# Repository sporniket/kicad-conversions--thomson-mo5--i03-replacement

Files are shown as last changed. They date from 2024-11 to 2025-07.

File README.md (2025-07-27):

# Replacement of I03 (color PROM) for the Thomson MO5

> [WARNING] Please read carefully this note before using this project. It contains important facts.

Content

1. What is **Replacement of I03 (color PROM) for the Thomson MO5**, and when to use it ?
2. What should you know before using **Replacement of I03 (color PROM) for the Thomson MO5** ?
3. How to use **Replacement of I03 (color PROM) for the Thomson MO5** ?
4. Known issues
5. Miscellanous

## 1. What is **Replacement of I03 (color PROM) for the Thomson MO5**, and when to use it ?

**Replacement of I03 (color PROM) for the Thomson MO5** replaces the PROM that is used to convert pixel colors represented as a 4 bits value (pastel, red, green, blue) and a supplemental bit for blanking signal, into a RGB-222 value and a supplemental trigger signal for the builtin analog video incrustation feature (requires a specific extension) of the Thomson MO5.

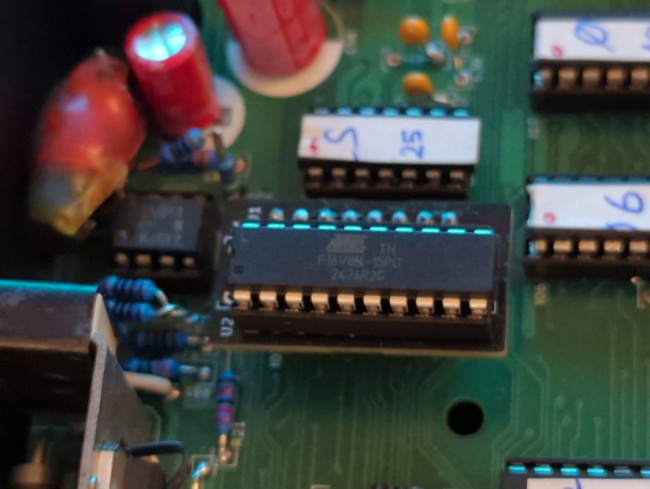
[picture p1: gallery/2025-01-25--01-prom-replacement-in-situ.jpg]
The replacement installed on the motherboard


### Licence

**Replacement of I03 (color PROM) for the Thomson MO5** is published under the Creative Commons CC0 license. You can find a copy of the licence there : https://creativecommons.org/publicdomain/zero/1.0/legalcode

You can copy, modify, distribute and perform the work, even for commercial purposes, all without asking permission.

**Replacement of I03 (color PROM) for the Thomson MO5** is distributed in the hope that it will be useful, but WITHOUT ANY WARRANTY; without even the implied warranty of MERCHANTABILITY or FITNESS FOR A PARTICULAR PURPOSE.

### Release notes

#### Release v2.0.0

* Resolves #6 : Add a breakout connector with R[1..2], V[1..2] and B[1..2] for adding custom DAC mods

Contains schematics in PDF files, gerber archive, and the JED file.

#### Release v1.0.0

Contains schematics in PDF files, gerber archive, and the JED file.

#### Release v1.0.0-rc1

**Hardware only** 

Contains schematics in PDF files, and gerber archive.

## 2. What should you know before using **Replacement of I03 (color PROM) for the Thomson MO5** ?

**Replacement of I03 (color PROM) for the Thomson MO5** is made of an hardware part to hold a GAL16v8 (or its current available compatible component ATF16v8) hereafter called "GAL", and a fusemap to be flashed onto said GAL.

* The hardware part is a Kicad 8 project describing the adapter from original chip socket in the computer motherboard
* The fusemap part is a source to be compiled by relevant tool to obtain a suitable JED fusemap.

> Do not use **Replacement of I03 (color PROM) for the Thomson MO5** if this project is not suitable for your project.

## 3. How to use **Replacement of I03 (color PROM) for the Thomson MO5** ?

### From sources

To get the latest available work, one must clone the git repository.

	git clone --recurse-submodules https://github.com/sporniket/kicad-conversions--thomson-mo5--i03-replacement.git

Then, open the project with Kicad 8.

To produce the fusemap... TO BE WRITTEN

## 4. Known issues
See the [project issues](https://github.com/sporniket/kicad-conversions--thomson-mo5--i03-replacement/issues) page.

## 5. Miscellanous

### Report issues
Use the [project issues](https://github.com/sporniket/kicad-conversions--thomson-mo5--i03-replacement/issues) page.

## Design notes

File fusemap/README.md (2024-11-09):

# Fusemap project

This folder will contains the source description of the fusemap to program into the GAL16v8 to be installed.

For now it is in a draft state (akin to a memo), and contains 2 versions :

* a GALasm compatible candidate description : prom.pld
* A Amaranth compatible candidate description : prom.py

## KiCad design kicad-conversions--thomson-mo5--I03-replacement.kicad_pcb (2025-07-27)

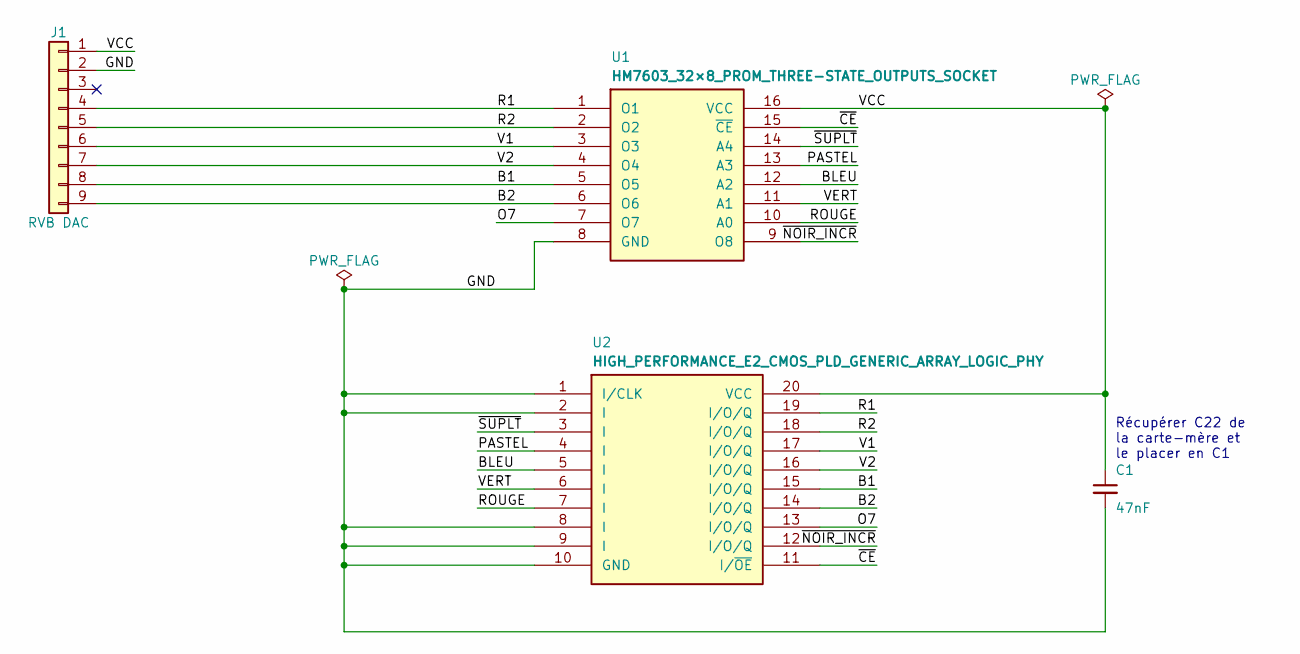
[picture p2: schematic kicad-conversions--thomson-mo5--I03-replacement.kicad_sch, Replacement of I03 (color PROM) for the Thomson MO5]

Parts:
C1: 47nF; Passive_THT_capacitor_mlcc_W2.54mm_L5.08mm
J1: RVB DAC; PinHeader_1x09_P2.54mm_Vertical
U1: HM7603_32×8_PROM_THREE-STATE_OUTPUTS_SOCKET; DIP-16_W7.62mm_LongPads
U2: HIGH_PERFORMANCE_E2_CMOS_PLD_GENERIC_ARRAY_LOGIC_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; DIP-20_W7.62mm_LongPads

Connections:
/B1: J1.8, U1.5 (O5), U2.15 (I/O/Q)
/B2: J1.9, U1.6 (O6), U2.14 (I/O/Q)
/BLEU: U1.12 (A2), U2.5 (I)
/GND: C1.2, J1.2, U1.8 (GND), U2.1 (I/CLK), U2.2 (I), U2.8 (I), U2.9 (I), U2.10 (GND)
/O7: U1.7 (O7), U2.13 (I/O/Q)
/PASTEL: U1.13 (A3), U2.4 (I)
/R1: J1.4, U1.1 (O1), U2.19 (I/O/Q)
/R2: J1.5, U1.2 (O2), U2.18 (I/O/Q)
/ROUGE: U1.10 (A0), U2.7 (I)
/V1: J1.6, U1.3 (O3), U2.17 (I/O/Q)
/V2: J1.7, U1.4 (O4), U2.16 (I/O/Q)
/VCC: C1.1, J1.1, U1.16 (VCC), U2.20 (VCC)
/VERT: U1.11 (A1), U2.6 (I)
/~CE: U1.15 (~CE), U2.11 (I/~OE)
/~NOIR_INCR: U1.9 (O8), U2.12 (I/O/Q)
/~SUPLT: U1.14 (A4), U2.3 (I)

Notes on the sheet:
Récupérer C22 de la carte-mère et le placer en C1

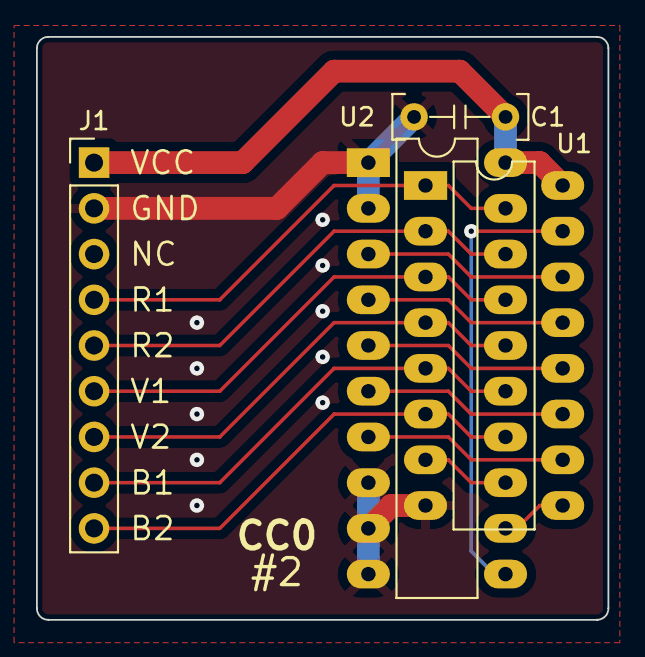
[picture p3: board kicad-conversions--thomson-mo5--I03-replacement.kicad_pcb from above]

Board: 2 copper layers, 31.8 x 32.4 mm, 4 parts (0 on the bottom side), 16 nets.

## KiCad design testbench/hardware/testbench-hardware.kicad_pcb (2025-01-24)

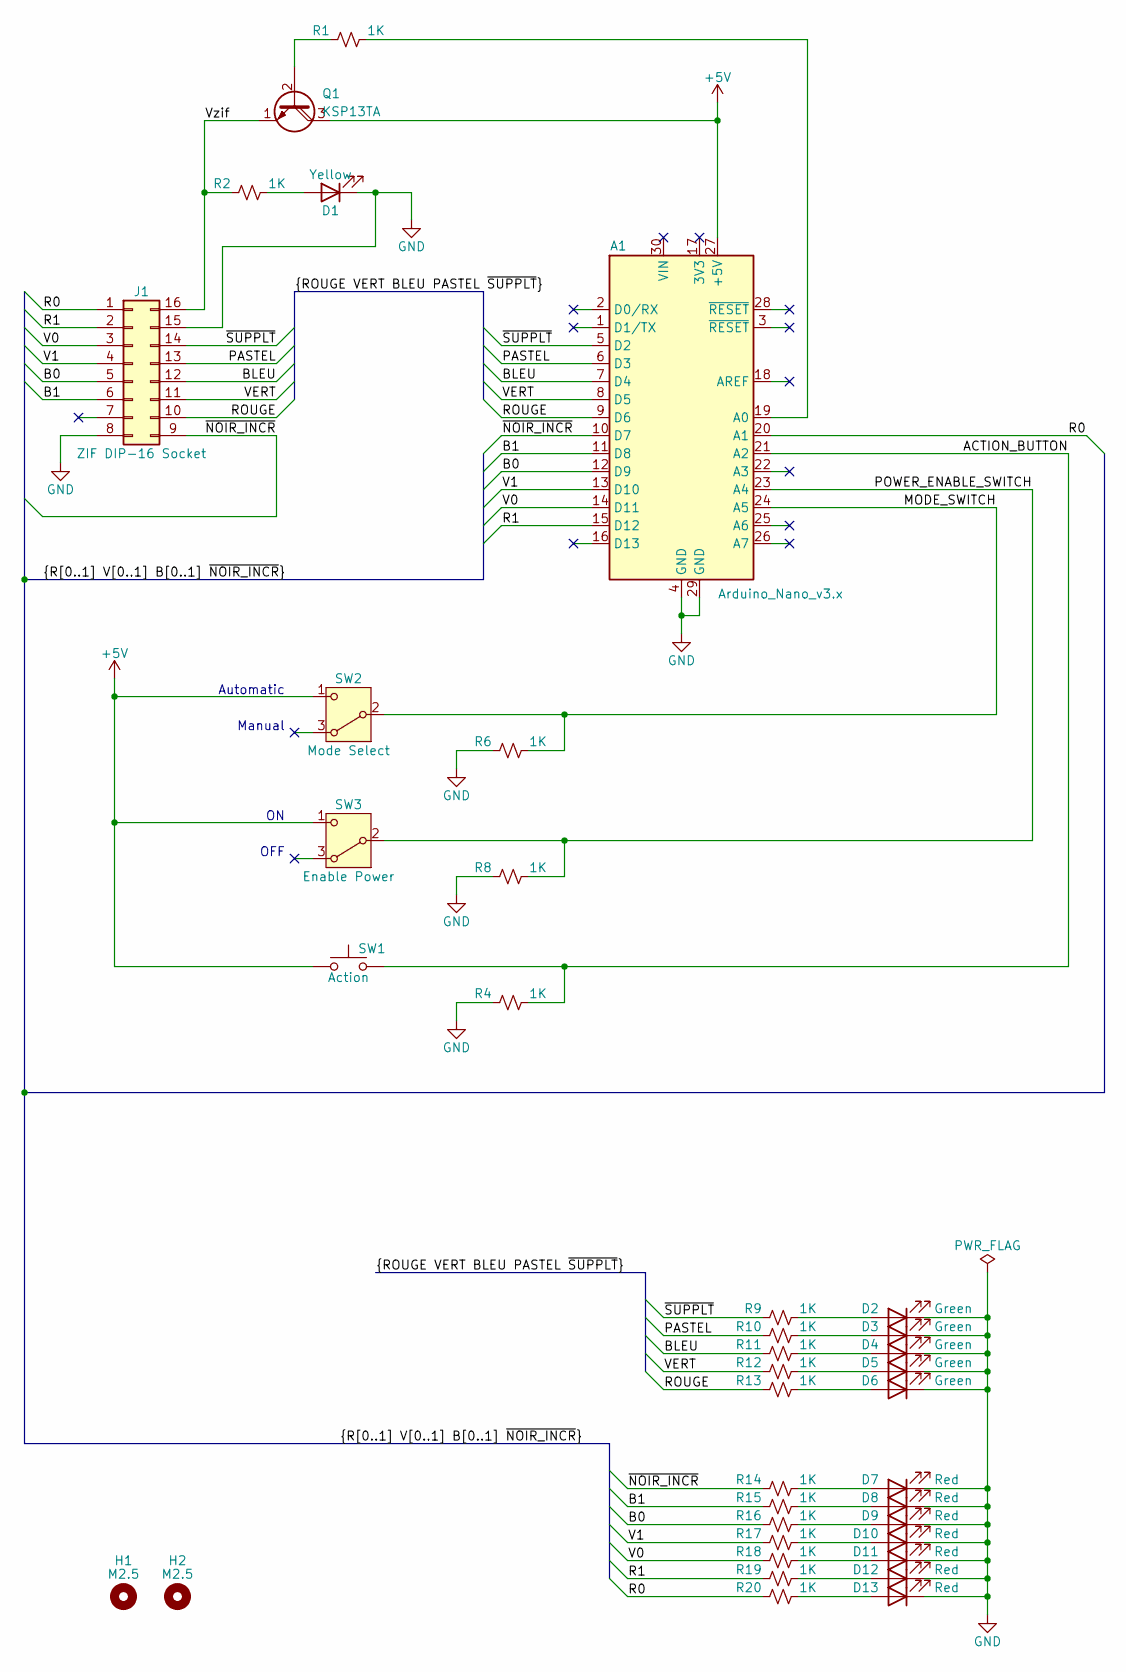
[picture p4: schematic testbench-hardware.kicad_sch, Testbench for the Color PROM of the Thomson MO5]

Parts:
A1: Arduino_Nano_v3.x; Arduino_Nano
D1: Yellow; LED_D3.0mm
D2, D3, D4, D5, D6: Green; LED_D3.0mm
D7, D8, D9, D10, D11, D12, D13: Red; LED_D3.0mm
H1, H2: M2.5; MountingHole_2.7mm_M2.5
J1: ZIF DIP-16 Socket; DIP-16_W7.62mm_Socket
Q1: KSP13TA; TO-92_Inline_Wide
R1, R2, R4, R6, R8, R9, R10, R11, R12, R13, R14, R15, R16, R17, R18, R19, R20: 1K; Passive_THT_resistor_W2.54mm_L12.70mm
SW1: Action; SW_PUSH-12mm
SW2: Mode Select; g-switch_22f12-gxxx--SPDT
SW3: Enable Power; g-switch_22f12-gxxx--SPDT

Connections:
+5V: A1.27 (+5V), Q1.3 (C), SW1.1, SW2.1 (C), SW3.1 (C)
/ACTION_BUTTON: A1.21 (A2), R4.2, SW1.2
/B0: A1.12 (D9), J1.5, R16.1
/B1: A1.11 (D8), J1.6, R15.1
/BLEU: A1.7 (D4), J1.12, R11.1
/MODE_SWITCH: A1.24 (A5), R6.2, SW2.2 (B)
/PASTEL: A1.6 (D3), J1.13, R10.1
/POWER_ENABLE_SWITCH: A1.23 (A4), R8.2, SW3.2 (B)
/R0: A1.20 (A1), J1.1, R20.1
/R1: A1.15 (D12), J1.2, R19.1
/ROUGE: A1.9 (D6), J1.10, R13.1
/V0: A1.14 (D11), J1.3, R18.1
/V1: A1.13 (D10), J1.4, R17.1
/VERT: A1.8 (D5), J1.11, R12.1
/Vzif: J1.16, Q1.1 (E), R2.1
/~NOIR_INCR: A1.10 (D7), J1.9, R14.1
/~SUPPLT: A1.5 (D2), J1.14, R9.1
GND: A1.4 (GND), A1.29 (GND), D1.1 (K), D2.1 (K), D3.1 (K), D4.1 (K), D5.1 (K), D6.1 (K), D7.1 (K), D8.1 (K), D9.1 (K), D10.1 (K), D11.1 (K), D12.1 (K), D13.1 (K), J1.8, J1.15, R4.1, R6.1, R8.1
unnamed: A1.19 (A0), R1.2
unnamed: D1.2 (A), R2.2
unnamed: D2.2 (A), R9.2
unnamed: D3.2 (A), R10.2
unnamed: D4.2 (A), R11.2
unnamed: D5.2 (A), R12.2
unnamed: D6.2 (A), R13.2
unnamed: D7.2 (A), R14.2
unnamed: D8.2 (A), R15.2
unnamed: D9.2 (A), R16.2
unnamed: D10.2 (A), R17.2
unnamed: D11.2 (A), R18.2
unnamed: D12.2 (A), R19.2
unnamed: D13.2 (A), R20.2
unnamed: Q1.2 (B), R1.1

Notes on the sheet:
Automatic
Manual
OFF

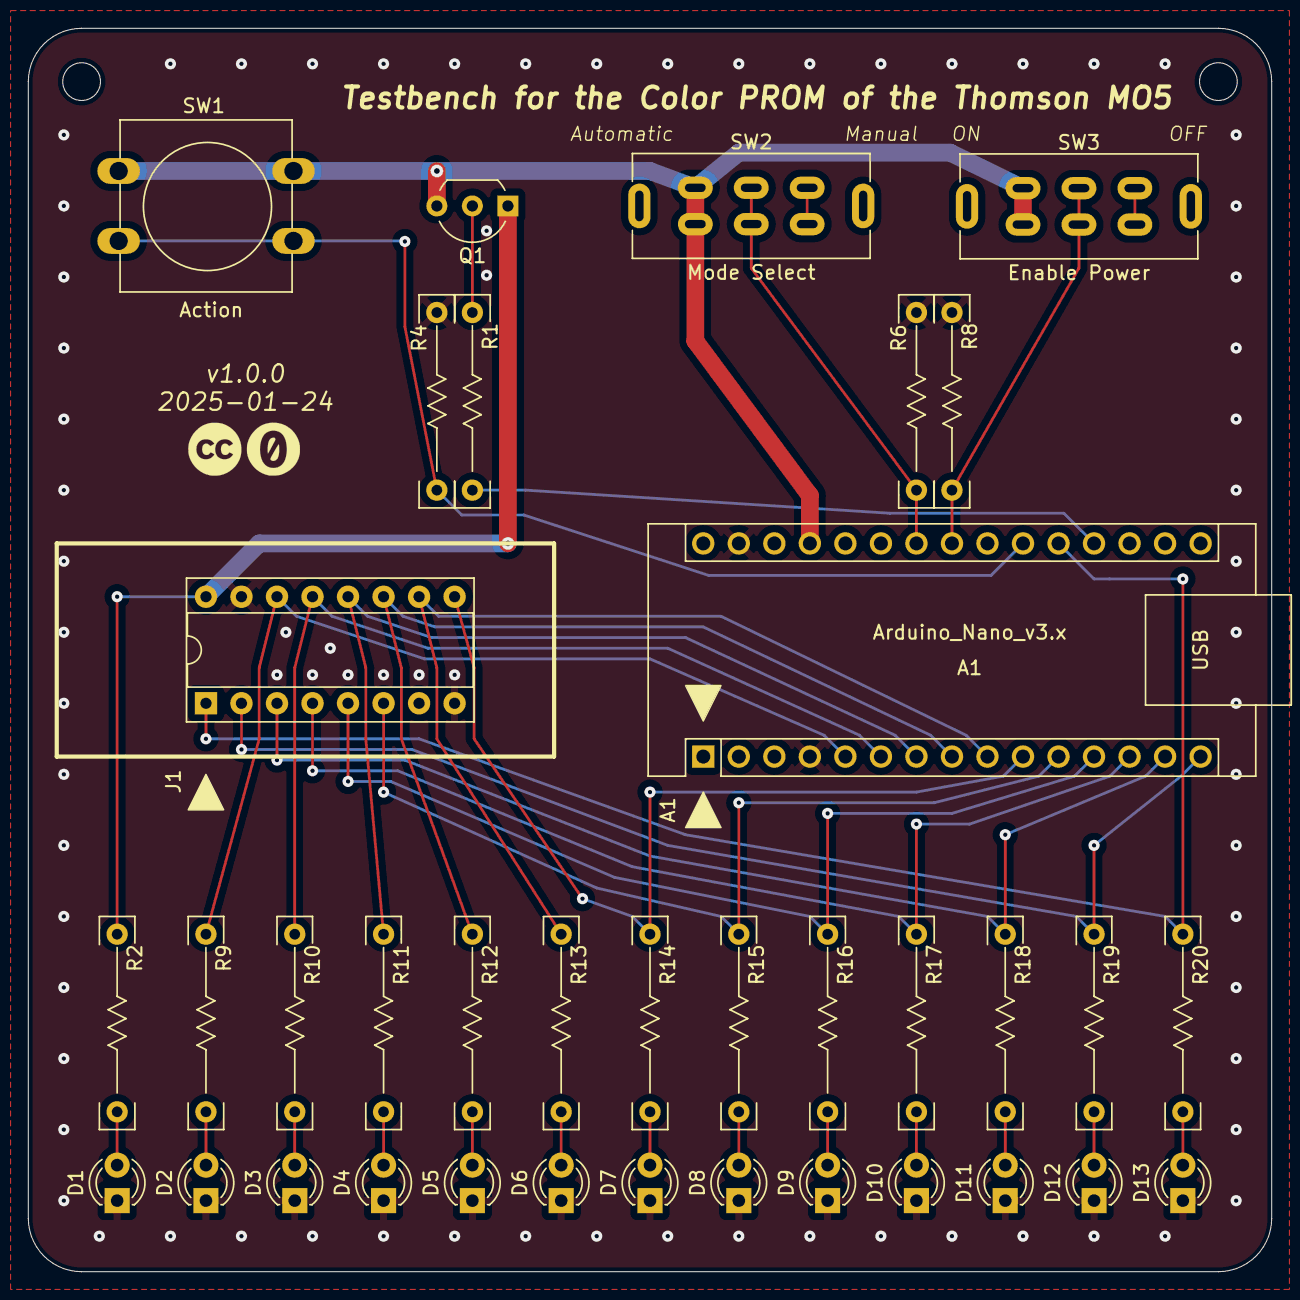
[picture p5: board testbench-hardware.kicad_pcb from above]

Board: 2 copper layers, 88.9 x 88.9 mm, 38 parts (0 on the bottom side), 33 nets.

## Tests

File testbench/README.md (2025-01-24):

# Testbench

The testbench allows to get data from an existing PROM, as well as checking data emitted by the replacement. Based on **Arduino Nano**, it consists of a hardware project, and a firmware project.

Design goals :

* a ZIF socket to swap devices under test
* The power supply of the device under test can be switched off ; the Arduino nano receives the switch command and enable/disable the power accordingly. It allows to swap devices without unplugging the testbench.
* Another switch for an "Automatic/Manual" mode.
* A push button to trigger an action that depends on the mode.
* Some LEDs to display :
  * whether the power supply of the device under test is on or off.
  * the address probed by the Arduino.
  * the data output of the device.
* The Arduino Nano send to the serial link the data read from the device under test, and display an OK/KO status with the onboard LED.

## Hardware project

**The schematic** is enough to build a device using prototype boards, or even breadboard, as I did. I have used a normal PNP transistor (rated with 500mA) from my parts box. Your mileage may vary.

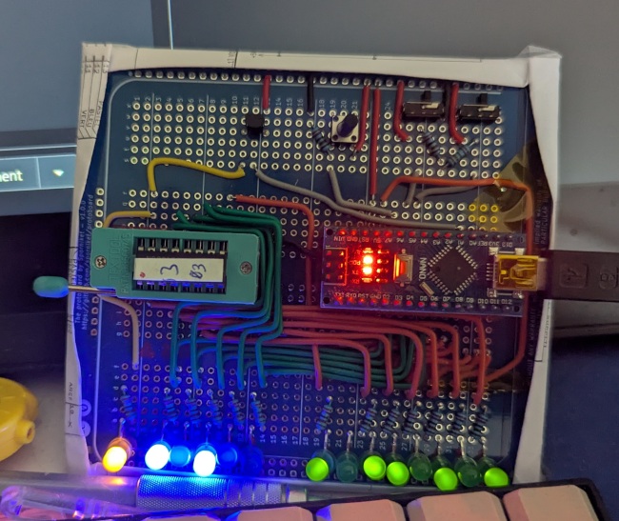
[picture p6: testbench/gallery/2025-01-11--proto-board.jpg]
the prototype board in action


**A pcb** is provided for convenience, it is not tested, but should be operationnal.

One particular parts for this PCB, selected because I have a lot of spares : the switches are [G-Switch SS-22F12-G060](https://www.lcsc.com/product-detail/Slide-Switches_G-Switch-SS-22F12-G060_C2848906.html)

The ZIF socket may be directly soldered, or plugged in a standard narrow DIP-16 socket, for easier servicing or recycling of this part.

## Firmware project

For now the implemented feature are :

* The power supply of the device under test can be switched on/off using the corresponding switch
* The address are probed continuously and the data is output to the serial. Open the serial monitor of the Arduino IDE to get the report.

That was enough to complete the main project.

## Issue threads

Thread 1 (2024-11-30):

[verification device] Create a verification device

sporniket, 2024-11-30:
# User story

**As** a logic designer

**I want** a device allowing to asserting the content of an original PROM or a programmed PLD reproducing said PROM

**In order to** quickly and easily validate my work, verify a batch of programmed PLD, and so on.

# Technical details

## Hardware design

* An Arduino Nano, plugged to an host computer ; the arduino send to the serial port a report of the verification.
* A ZIF socket to hold the 16 pins, DIP package original PROM. Any PLD MUST be plugged onto an adapter in order to verify that it will work as a drop-in replacement.
* Five data lines are driven _by the Arduino_, link the Arduino to the address lines of the PROM (`/SUPLT`, `RED`, `GREEN`, `BLUE` and `PASTEL`) and also drive 5 _green_ leds, 7 data lines are driven _by the PROM_(`R[0:1]`,`G[0:1]`,`B[0:1]`, `/NOIR_INCR`), and also drive 7 _red_leds.
* A toggle switch allow to enable/disable the verification (cut the power supply to the PROM) to allow changing the PROM. A _yellow_ led indicates when the PROM is supplied with power. The arduino is in charge of cutting the power by driving e.g. a mosfet.
* A toggle switch allow to change mode between automatic and manual
* A push button allow to cycle the address when in manual mode

# Verification tests

## Enable/disable the verification

**When** the enable/disable switch is asserted,

**Then** the witness LED is lit, and there is a voltage between the VCC and GND pins of the socket

**When** the enable/disable switch is negated,

**Then** the witness LED is switched off, and there is no voltage between the VCC and GND pins of the socket

## Manual mode

**When** the mode switched is asserted (manual)

**Then** the address is cycled using a push of the button.

**Then** maintaining the push button pushed cycle the address 3 times per seconds

sporniket, 2025-01-11:
With a prototype board and a prototype firmware that simply cycle through the addresses and print to Serial the values (as C++ statements), I got :

```cpp
// Report
data_of_prom[0 /* 0 */ ] = 0b0 ; // 	 0h0 	// 0
data_of_prom[1 /* 1 */ ] = 0b0 ; // 	 0h0 	// 0
data_of_prom[2 /* 10 */ ] = 0b0 ; // 	 0h0 	// 0
data_of_prom[3 /* 11 */ ] = 0b0 ; // 	 0h0 	// 0
data_of_prom[4 /* 100 */ ] = 0b0 ; // 	 0h0 	// 0
data_of_prom[5 /* 101 */ ] = 0b0 ; // 	 0h0 	// 0
data_of_prom[6 /* 110 */ ] = 0b0 ; // 	 0h0 	// 0
data_of_prom[7 /* 111 */ ] = 0b0 ; // 	 0h0 	// 0
data_of_prom[8 /* 1000 */ ] = 0b0 ; // 	 0h0 	// 0
data_of_prom[9 /* 1001 */ ] = 0b0 ; // 	 0h0 	// 0
data_of_prom[10 /* 1010 */ ] = 0b0 ; // 	 0h0 	// 0
data_of_prom[11 /* 1011 */ ] = 0b0 ; // 	 0h0 	// 0
data_of_prom[12 /* 1100 */ ] = 0b0 ; // 	 0h0 	// 0
data_of_prom[13 /* 1101 */ ] = 0b0 ; // 	 0h0 	// 0
data_of_prom[14 /* 1110 */ ] = 0b0 ; // 	 0h0 	// 0
data_of_prom[15 /* 1111 */ ] = 0b0 ; // 	 0h0 	// 0
data_of_prom[16 /* 10000 */ ] = 0b0 ; // 	 0h0 	// 0
data_of_prom[17 /* 10001 */ ] = 0b10000010 ; // 	 0h82 	// 130
data_of_prom[18 /* 10010 */ ] = 0b10001100 ; // 	 0h8C 	// 140
data_of_prom[19 /* 10011 */ ] = 0b10001110 ; // 	 0h8E 	// 142
data_of_prom[20 /* 10100 */ ] = 0b10110100 ; // 	 0hB4 	// 180
data_of_prom[21 /* 10101 */ ] = 0b10110010 ; // 	 0hB2 	// 178
data_of_prom[22 /* 10110 */ ] = 0b10111100 ; // 	 0hBC 	// 188
data_of_prom[23 /* 10111 */ ] = 0b10111110 ; // 	 0hBE 	// 190
data_of_prom[24 /* 11000 */ ] = 0b10101010 ; // 	 0hAA 	// 170
data_of_prom[25 /* 11001 */ ] = 0b10101010 ; // 	 0hAA 	// 170
data_of_prom[26 /* 11010 */ ] = 0b10101110 ; // 	 0hAE 	// 174
data_of_prom[27 /* 11011 */ ] = 0b10101110 ; // 	 0hAE 	// 174
data_of_prom[28 /* 11100 */ ] = 0b10111000 ; // 	 0hB8 	// 184
data_of_prom[29 /* 11101 */ ] = 0b10111010 ; // 	 0hBA 	// 186
data_of_prom[30 /* 11110 */ ] = 0b10111110 ; // 	 0hBE 	// 190
data_of_prom[31 /* 11111 */ ] = 0b10011010 ; // 	 0h9A 	// 154
```

sporniket, 2025-01-23:
The firmware outputs nicer report (aligned values)

```cpp

// BEGIN Content of the color PROM of the Thomson MO5
uint8_t data_of_prom[32] ;
data_of_prom[ 0 /* 00000 */ ] = 0b00000000 ; // 0h00 //   0
data_of_prom[ 1 /* 00001 */ ] = 0b00000000 ; // 0h00 //   0
data_of_prom[ 2 /* 00010 */ ] = 0b00000000 ; // 0h00 //   0
data_of_prom[ 3 /* 00011 */ ] = 0b00000000 ; // 0h00 //   0
data_of_prom[ 4 /* 00100 */ ] = 0b00000000 ; // 0h00 //   0
data_of_prom[ 5 /* 00101 */ ] = 0b00000000 ; // 0h00 //   0
data_of_prom[ 6 /* 00110 */ ] = 0b00000000 ; // 0h00 //   0
data_of_prom[ 7 /* 00111 */ ] = 0b00000000 ; // 0h00 //   0
data_of_prom[ 8 /* 01000 */ ] = 0b00000000 ; // 0h00 //   0
data_of_prom[ 9 /* 01001 */ ] = 0b00000000 ; // 0h00 //   0
data_of_prom[10 /* 01010 */ ] = 0b00000000 ; // 0h00 //   0
data_of_prom[11 /* 01011 */ ] = 0b00000000 ; // 0h00 //   0
data_of_prom[12 /* 01100 */ ] = 0b00000000 ; // 0h00 //   0
data_of_prom[13 /* 01101 */ ] = 0b00000000 ; // 0h00 //   0
data_of_prom[14 /* 01110 */ ] = 0b00000000 ; // 0h00 //   0
data_of_prom[15 /* 01111 */ ] = 0b00000000 ; // 0h00 //   0
data_of_prom[16 /* 10000 */ ] = 0b00000000 ; // 0h00 //   0
data_of_prom[17 /* 10001 */ ] = 0b00000011 ; // 0h03 //   3
data_of_prom[18 /* 10010 */ ] = 0b00001100 ; // 0h0C //  12
data_of_prom[19 /* 10011 */ ] = 0b00001111 ; // 0h0F //  15
data_of_prom[20 /* 10100 */ ] = 0b00110101 ; // 0h35 //  53
data_of_prom[21 /* 10101 */ ] = 0b00110011 ; // 0h33 //  51
data_of_prom[22 /* 10110 */ ] = 0b00111101 ; // 0h3D //  61
data_of_prom[23 /* 10111 */ ] = 0b00111111 ; // 0h3F //  63
data_of_prom[24 /* 11000 */ ] = 0b00101010 ; // 0h2A //  42
data_of_prom[25 /* 11001 */ ] = 0b00101011 ; // 0h2B //  43
data_of_prom[26 /* 11010 */ ] = 0b00101110 ; // 0h2E //  46
data_of_prom[27 /* 11011 */ ] = 0b00101111 ; // 0h2F //  47
data_of_prom[28 /* 11100 */ ] = 0b00111001 ; // 0h39 //  57
data_of_prom[29 /* 11101 */ ] = 0b00111011 ; // 0h3B //  59
data_of_prom[30 /* 11110 */ ] = 0b00111110 ; // 0h3E //  62
data_of_prom[31 /* 11111 */ ] = 0b00011011 ; // 0h1B //  27
// END Content of the color PROM of the Thomson MO5

```

sporniket, 2025-07-27:
Done with 5a3f3795525769a10589e01533b8c686d0e61636

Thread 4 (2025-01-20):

[bug][testbench][firmware] A6 and A7 cannot be used as digital input

sporniket, 2025-01-20:
_follows #2_

Change the firmware accordingly to the schematic

Closed 2025-01-22.

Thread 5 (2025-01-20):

[testbench][hardware] Change Q1 to a Darlington

sporniket, 2025-01-20:
As power switch, a Darlington is more efficient than a simple BJT :
* less strain on microcontroller pin to base
* less power dissipation

see this video : https://www.youtube.com/watch?v=TNfxmxt6RMw

Closed 2025-01-21.

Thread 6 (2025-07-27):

Add a breakout connector with R[1..2], V[1..2] and B[1..2] for adding custom DAC mods

sporniket, 2025-07-27:
The original DAC of the Thomson MO5 for converting red/green/blue digital values (2 bits) into analogic values is suited for CRT TV sets of the time, but nowadays the signal is too high for current LCD TV sets and pastel colors are almost indistinguishable from white.

In order to design a new dac and bypass the old one, provide a breakout connector (a single row of 0.1mils pitched header pin receptacles) with :
* VCC, GND
* R[1..2]
* V[1..2]
* B[1..2]

Thus 8 contacts.

Make it keyed to avoid reverse connection, e.g. :
VCC, GND, KEY(missing hole), R[1..2],V[1..2],B[1..2]

Closed 2025-07-27.

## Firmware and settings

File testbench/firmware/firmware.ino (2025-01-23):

// =====================================================
// ___       ___
//  |  |__| |__
//  |  |  | |___
//
// ___       __         __   __                 __   __
//  |  |__| /  \  |\/| /__` /  \ |\ |     |\/| /  \ /__
//  |  |  | \__/  |  | .__/ \__/ | \|     |  | \__/ .__)
//
//  __   __        __   __      __   __   __
// /  ` /  \ |    /  \ |__)    |__) |__) /  \  |\/|
// \__, \__/ |___ \__/ |  \    |    |  \ \__/  |  |
//
// ___  ___  __  ___  __   ___       __
//  |  |__  /__`  |  |__) |__  |\ | /  ` |__|
//  |  |___ .__/  |  |__) |___ | \| \__, |  |
//
// =====================================================
// (c)2024-2025 David SPORN
// SPDX-License-Identifier: CC0-1.0
// =====================================================

// =====================================================
// Management variables
// =====================================================

// ---
// Main loop phases, alternating between read and write phases
// ---
#include "phaseman.h"

// ---
// Status LED (the onboard LED) management
// ---
#include "StatusLed.h"

// ---
// Data report sent to serial
// ---
#include "Report.h"

// ---
// Management of GPIOs
// ---
// GPIOs are used for 4 tasks :
// * Enabling/disabling the power supply for the device under test. Disabling
// the power supply allow to swap the device to test.
// * Select the address sent to the device under test
// * Read the data from the device under test
// * User inputs (one action button and two toggle switches)
// ---

// -- address pins
#include "Address.h"

// -- data pins
#include "Data.h"

// -- Power control pins (outputs) : A0
const uint8_t POWER_CONTROL_PINS[] = {A0};
const uint8_t sizeof_POWER_CONTROL_PINS =
    sizeof(POWER_CONTROL_PINS) / sizeof(POWER_CONTROL_PINS[0]);

// -- user input pins (buttons and toggle switches) : A2, A5-A4 ;
const uint8_t INPUT_PINS[] = {A2, A5, A4};
const uint8_t sizeof_INPUT_PINS = sizeof(INPUT_PINS) / sizeof(INPUT_PINS[0]);

// -- -- A2 = Action push-button
const uint8_t INPUT_PIN_ACTION = 0;
bool on_action = false;
uint8_t action_value = LOW;
const uint8_t ACTION_COOLDOWN_START = 3;
uint8_t action_cooldown = ACTION_COOLDOWN_START;
bool action_is_performing = false;
uint8_t action_remaining = 0;

// -- -- A5 = Mode toggle ; 0-> Manual, 1-> Automatic
const uint8_t INPUT_PIN_MODE_TOGGLE = 1;
bool onchange_mode = false;
uint8_t mode_value = LOW;

// -- -- A4 = Enable power toggle ; 0-> OFF, 1-> ON
const uint8_t INPUT_PIN_POWER_ENABLE = 2;
bool onchange_powerEnable = false;
uint8_t powerEnable_value = LOW;

// =====================================================
// Prepare...
// =====================================================

void setup() {
  // -- onboard LED
  pinMode(LED_BUILTIN, OUTPUT);

  // -- other setups
  setupGpios();
  setupSerial();
  StatusLed_toPass();
}

void setupGpios() {
  Address_setupGpios();
  Data_setupGpios();

  // -- power control pins
  for (uint8_t i = 0; i < sizeof_POWER_CONTROL_PINS; i++) {
    pinMode(POWER_CONTROL_PINS[i], OUTPUT);
    digitalWrite(POWER_CONTROL_PINS[i], LOW);
  }

  // -- user input pins
  for (uint8_t i = 0; i < sizeof_INPUT_PINS; i++) {
    pinMode(INPUT_PINS[i], INPUT);
  }
}

void setupSerial() {
  Serial.begin(9600);
  while (!Serial) {
    ; // wait for serial port to connect. Needed for native USB port only
  }
}

// =====================================================
// Main loop
// =====================================================

void loop() { loopPhases(); }

void handleReadPhase() {
  Data_read();
  Report_registerValue(Address_value, Data_value);

  if (action_is_performing && LOW == mode_value) {
    Report_emitSingleValue(Address_value);
  }

  // -- read user input pins
  on_action = readInputButton(INPUT_PIN_ACTION, action_value);
  onchange_mode = readToggleSwitch(INPUT_PIN_MODE_TOGGLE, mode_value);
  onchange_powerEnable =
      readToggleSwitch(INPUT_PIN_POWER_ENABLE, powerEnable_value);
}

bool readInputButton(uint8_t button, uint8_t &value) {
  const uint8_t in = digitalRead(INPUT_PINS[button]);
  bool trigger = (HIGH == in && LOW == value);
  value = in;
  return trigger;
}

bool readToggleSwitch(uint8_t toggle, uint8_t &value) {
  const uint8_t in = digitalRead(INPUT_PINS[toggle]);
  bool onchange = (in != value);
  value = in;
  return onchange;
}

void handleWritePhase() {
  // Code to update outputs
  updateStatusLed();
  handlePower();
  handleAction();
}

void handlePower() {
  if (!onchange_powerEnable)
    return;

  for (uint8_t i = 0;
       i < sizeof(POWER_CONTROL_PINS) / sizeof(POWER_CONTROL_PINS[0]); i++) {
    digitalWrite(POWER_CONTROL_PINS[i], powerEnable_value);
  }
}

void handleAction() {
  // the handling is bogus, for now just
  // emitSingleReport/incrementAddress/emitAddress
  Report_emitSingleValue(Address_value);
  Address__loop();
  return;

  // skip that
  if (action_is_performing) {
    if (action_remaining > 0) {
      --action_remaining;
    } else if (0 == Address_value) {
      Report_emitFull();
      action_is_performing = false;
    }
    Address__loop();
  }
  if (action_cooldown > 0) {
    Serial.println("// -- cooldown > 0");
    --action_cooldown;
    return;
  }
  if (!on_action) {
    Serial.println("// -- on_action is false");
    if (action_value == LOW) {
      Serial.println("// -- action_value is LOW");
    } else {
      Serial.println("// -- action_value is HIGH");
    }
    return;
  } else {
    Serial.println("// -- on_action is true");
  }

  if (LOW == mode_value) // manual mode
    handleAction_manual();
  else
    handleAction_auto();
}

void handleAction_manual() {
  // TODO
  Address__loop();
  action_is_performing = true;
}

void handleAction_auto() {
  if (!action_is_performing) {
    Address_value = 0;
    action_is_performing = true;
    action_remaining = 1;
  }
}

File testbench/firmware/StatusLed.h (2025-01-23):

// =====================================================
// ___       ___
//  |  |__| |__
//  |  |  | |___
//
// ___       __         __   __                 __   __
//  |  |__| /  \  |\/| /__` /  \ |\ |     |\/| /  \ /__
//  |  |  | \__/  |  | .__/ \__/ | \|     |  | \__/ .__)
//
//  __   __        __   __      __   __   __
// /  ` /  \ |    /  \ |__)    |__) |__) /  \  |\/|
// \__, \__/ |___ \__/ |  \    |    |  \ \__/  |  |
//
// ___  ___  __  ___  __   ___       __
//  |  |__  /__`  |  |__) |__  |\ | /  ` |__|
//  |  |___ .__/  |  |__) |___ | \| \__, |  |
//
// =====================================================
// (c)2024-2025 David SPORN
// SPDX-License-Identifier: CC0-1.0
// =====================================================

// ---
// Status LED (the onboard LED) management
// ---
// The status LED is either a solid light (nothing to report)
// or an animated blinking to report an OK (the data read from
// an address is the same value as expected) or a KO (data read
// from an address is different from expected value).
// ---
// Animations are described by an array of 10 values (HIGH or LOW),
// the LED is updated ten times per seconds, thus each step is displayed
// for 1/10 of second.

// The OK animation is two quick blinks then a long pause.
uint8_t STATUS_LED_SEQUENCE_PASS[] = {HIGH, LOW, HIGH, LOW, LOW,
                                      LOW,  LOW, LOW,  LOW, LOW};

// The KO animation is a slow, 50% duty cycle blink.
uint8_t STATUS_LED_SEQUENCE_WRONG[] = {HIGH, HIGH, HIGH, HIGH, HIGH,
                                       LOW,  LOW,  LOW,  LOW,  LOW};

// ---
// Animation designators
enum StatusLedAnimation { NONE, PASS, WRONG };

StatusLedAnimation StatusLed_animation = PASS;

// -- We keep track of the actual sequence
uint8_t *StatusLed_sequence = STATUS_LED_SEQUENCE_PASS;

// ---
// Animation management
// -- The current step of the animation
uint8_t StatusLed_index = 9;

// -- The limit on which one goes back to step 0
const uint8_t STATUS_LED_INDEX_MAX = 10;

// ** Change and resets the animation sequence.
void StatusLed__changeAnimation(StatusLedAnimation animation) {
  StatusLed_animation = animation;
  StatusLed_index = 9;
  StatusLed_sequence = (StatusLedAnimation::PASS) ? STATUS_LED_SEQUENCE_PASS
                                                  : STATUS_LED_SEQUENCE_WRONG;
}

// ** alias to `StatusLed_changeAnimation(StatusLedAnimation::PASS)`
void StatusLed_toPass() {
  StatusLed__changeAnimation(StatusLedAnimation::PASS);
}

// ** alias to `StatusLed_changeAnimation(StatusLedAnimation::WRONG)`
void StatusLed_toWrong() {
  StatusLed__changeAnimation(StatusLedAnimation::WRONG);
}

// ** alias to `StatusLed_changeAnimation(StatusLedAnimation::NONE)`
void StatusLed_toNone() {
  StatusLed__changeAnimation(StatusLedAnimation::NONE);
}

// ** Cycle through the animation steps.
void StatusLed_animate() {
  StatusLed_index++;
  if (StatusLed_index >= STATUS_LED_INDEX_MAX) {
    StatusLed_index = 0;
  }
}

// ** Update the status led.
void updateStatusLed() {
  StatusLed_animate();
  switch (StatusLed_animation) {
  case NONE: {
    // just switch on the LED
    digitalWrite(LED_BUILTIN, HIGH);
    break;
  }
  default:
    if (StatusLed_sequence[StatusLed_index]) {
      digitalWrite(LED_BUILTIN, HIGH);
    } else {
      digitalWrite(LED_BUILTIN, LOW);
    }
  }
}

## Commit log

2024-11-03 done schematic
    [kicad-conversions--thomson-mo5--I03-replacement.kicad_sch]
2024-11-03 reference my self-made footprints
2024-11-03 assign footprint to capacitor
    [kicad-conversions--thomson-mo5--I03-replacement.kicad_pcb, kicad-conversions--thomson-mo5--I03-replacement.kicad_sch]
2024-11-03 import pcb settings from main board
    [kicad-conversions--thomson-mo5--I03-replacement.kicad_pcb]
2024-11-03 done wiring
    [kicad-conversions--thomson-mo5--I03-replacement.kicad_pcb, kicad-conversions--thomson-mo5--I03-replacement.kicad_sch]
2024-11-03 final adjustments
    [kicad-conversions--thomson-mo5--I03-replacement.kicad_pcb]
2024-11-04 schematic -- rename wires with functionnal names
    [kicad-conversions--thomson-mo5--I03-replacement.kicad_pcb, kicad-conversions--thomson-mo5--I03-replacement.kicad_sch]
2024-11-09 drafts of fusemap description
2024-11-09 added proper description in schematic, pcb
    [kicad-conversions--thomson-mo5--I03-replacement.kicad_pcb, kicad-conversions--thomson-mo5--I03-replacement.kicad_sch]
2024-11-09 export release files
    [kicad-conversions--thomson-mo5--I03-replacement.kicad_pcb, kicad-conversions--thomson-mo5--I03-replacement.kicad_sch]
2024-12-06 testbench -- hardware schematic
    [testbench-hardware.kicad_pcb, testbench-hardware.kicad_sch]
2024-12-06 [testbench] no ERC violations
    [testbench-hardware.kicad_sch]
2024-12-06 [testbench] pcb layout
    [testbench-hardware.kicad_pcb, testbench-hardware.kicad_sch]
2024-12-07 [testbench] start wiring
    [testbench-hardware.kicad_pcb, testbench-hardware.kicad_sch]
2024-12-07 [testbench] done wiring
    [testbench-hardware.kicad_pcb]
2024-12-07 [testbench] labels, cc-0 logos, tweak routing
    [testbench-hardware.kicad_pcb]
2024-12-09 [testbench] mounting holes
    [testbench-hardware.kicad_pcb, testbench-hardware.kicad_sch]
2024-12-09 [testbench] labels and marking adjustments
    [testbench-hardware.kicad_pcb]
2024-12-10 [testbench] uses DPDT switches as SPDT switches for nicer routing
    [testbench-hardware.kicad_pcb, testbench-hardware.kicad_sch]
2025-01-17 [testbench] fixes bugs, impact of #2, better report
    [firmware.ino]
2025-01-17 [fusemap] refactor, and rework logic
2025-01-17 [fusemap] reworked green logic
2025-01-17 [fusemap] reworked red logic
2025-01-17 [fusemap] fixed typos
2025-01-18 [fusemap] fixed prom.pld, the problem was a wrong mapping for input pins
2025-01-20 Fixes #2 : [bug][testbench][hardware] A6 and A7 cannot be used as digital input
    [testbench-hardware.kicad_pcb, testbench-hardware.kicad_sch]
2025-01-20 [testbench][hardware] Tweaked the layout of some traces
    [testbench-hardware.kicad_pcb]
2025-01-20 Fixes #3 : [bug][testbench] remove R3, R5 and R7
    [testbench-hardware.kicad_pcb, testbench-hardware.kicad_sch]
2025-01-21 Resolves #5 : [testbench][hardware] Change Q1 to a Darlington
    [testbench-hardware.kicad_sch]
2025-01-22 Fixes #4 : [bug][testbench][firmware] A6 and A7 cannot be used as digital input
    [firmware.ino]
2025-01-23 [testbench][firmware] refactor onboard led management
2025-01-23 [testbench][firmware] Refactor gpio driver for address
2025-01-23 [testbench][firmware] Refactor gpio driver for data
2025-01-24 [testbench][hardware] bump version and revision date
    [testbench-hardware.kicad_pcb, testbench-hardware.kicad_sch]
2025-01-24 [testbench][hardware] change position of R1, R4, R6, R8 for nicer traces
    [testbench-hardware.kicad_pcb]
2025-01-25 prepare release : readme, date and rev of kicad files
    [kicad-conversions--thomson-mo5--I03-replacement.kicad_pcb, kicad-conversions--thomson-mo5--I03-replacement.kicad_sch]
2025-07-27 Resolves #6 : Add a breakout connector with R[1..2], V[1..2] and B[1..2] for adding custom DAC mods
    [kicad-conversions--thomson-mo5--I03-replacement.kicad_pcb, kicad-conversions--thomson-mo5--I03-replacement.kicad_sch]
